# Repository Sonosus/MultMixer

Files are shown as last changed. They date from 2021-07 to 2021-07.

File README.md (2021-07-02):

# MultMixer
[][cc-by-sa]
hits (https://hits.deltapapa.io)

This is a Kosmo format module that is a combined buffered multiple and mixer. 
The multiple section has 1 input, 5 outputs, and an LED. The input is buffered to the 5 outputs, and the LED is used to show the state of the signal.

In the mixer section, there are 5 inputs and one output. Each input has its own pot and switch. The pot acts as an attenuator, and the switch disconnects that input from the main output. 





This module is based on the [LMNC Buffered Multiple](https://www.lookmumnocomputer.com/1161-buffered-multiple) and the [LMNC Mini Mixer](https://www.lookmumnocomputer.com/projects#/1163-mini-mixer). Much credit to Sam for open-sourcing his modules!

Interactive BOM [here](https://htmlpreview.github.io/?https://github.com/Sonosus/MultMixer/blob/main/Docs/MultMixer.html)

This work is licensed under a
[Creative Commons Attribution-ShareAlike 4.0 International License][cc-by-sa].

[][cc-by-sa]

[cc-by-sa]: http://creativecommons.org/licenses/by-sa/4.0/
[cc-by-sa-image]: https://licensebuttons.net/l/by-sa/4.0/88x31.png
[cc-by-sa-shield]: https://img.shields.io/badge/License-CC%20BY--SA%204.0-lightgrey.svg

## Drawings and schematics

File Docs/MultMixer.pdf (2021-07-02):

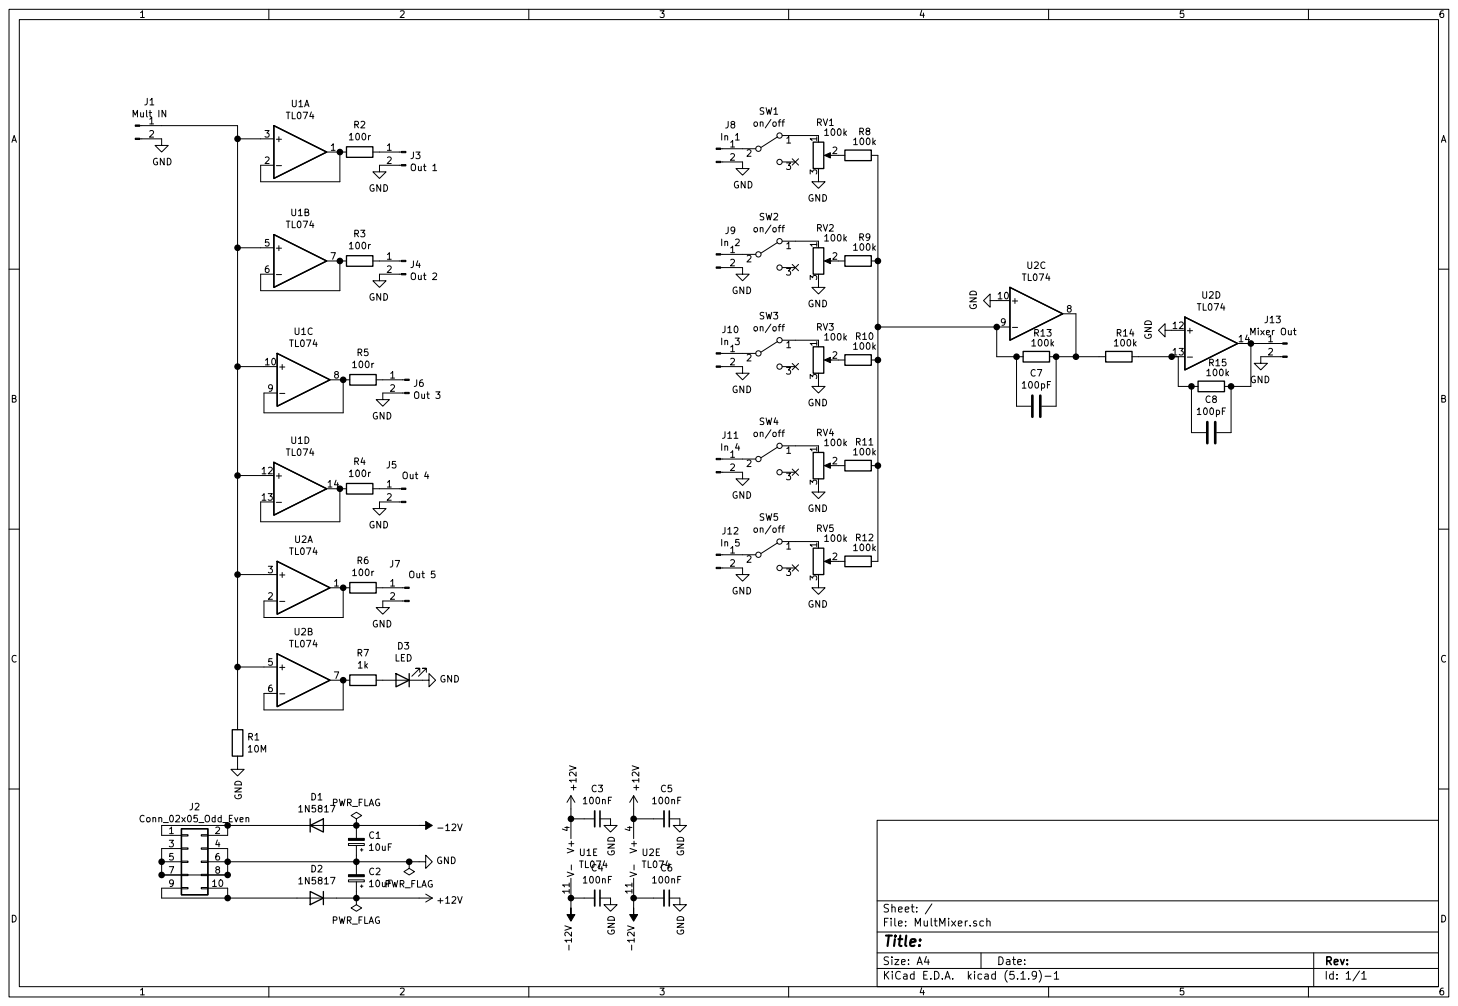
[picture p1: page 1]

Id: 1/1 Title: File: MultMixer.sch Sheet: /

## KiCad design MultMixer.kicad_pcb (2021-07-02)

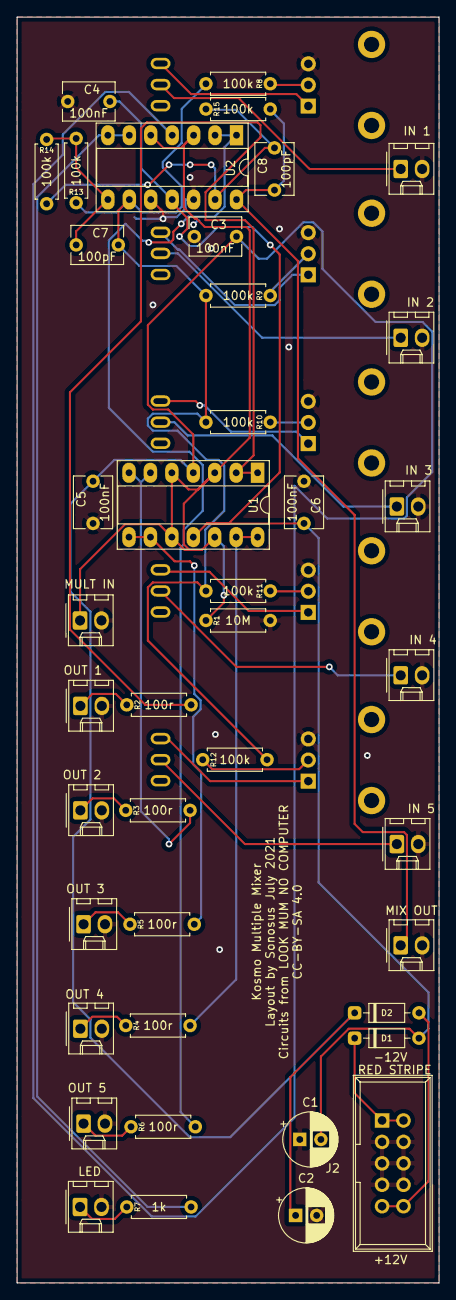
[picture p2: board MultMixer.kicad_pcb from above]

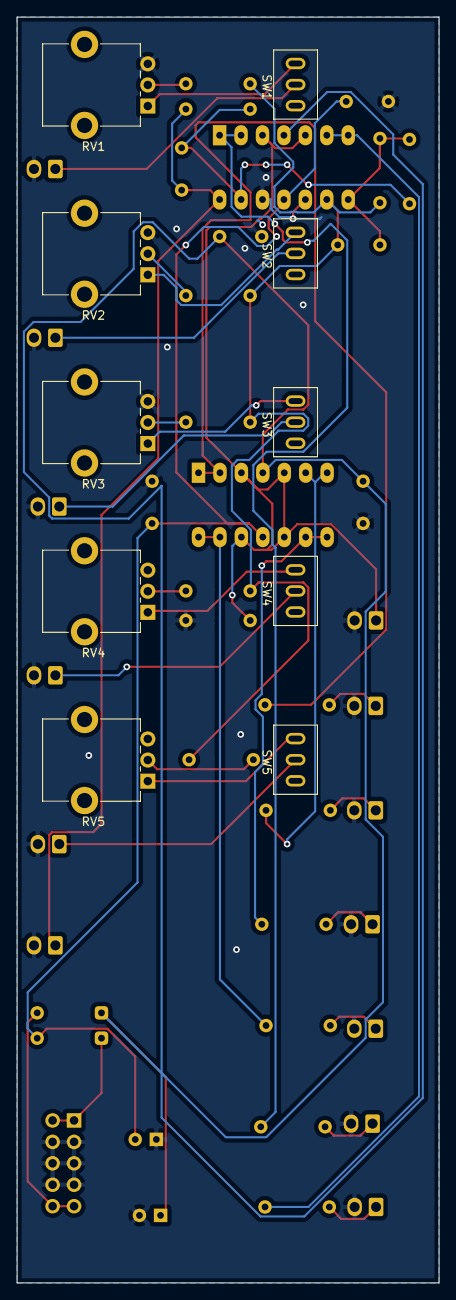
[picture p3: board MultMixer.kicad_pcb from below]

Board: 2 copper layers, 50.0 x 150.0 mm, 51 parts (10 on the bottom side), 37 nets.

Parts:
C1, C2: 10uF; Capacitor_Polarized
C3, C4, C5, C6: 100nF; Capacitor_NonPolarized
C7, C8: 100pF; Capacitor_NonPolarized
D1, D2: 1N5817; Diode_DO-35
IN 1: In 1; Molex_KK-254_AE-6410-02A_1x02_P2.54mm_Vertical
IN 2: In 2; Molex_KK-254_AE-6410-02A_1x02_P2.54mm_Vertical
IN 3: In 3; Molex_KK-254_AE-6410-02A_1x02_P2.54mm_Vertical
IN 4: In 4; Molex_KK-254_AE-6410-02A_1x02_P2.54mm_Vertical
IN 5: In 5; Molex_KK-254_AE-6410-02A_1x02_P2.54mm_Vertical
J2: Conn_02x05_Odd_Even; Power_Header
LED: LED; Molex_KK-254_AE-6410-02A_1x02_P2.54mm_Vertical
MIX OUT: Mixer Out; Molex_KK-254_AE-6410-02A_1x02_P2.54mm_Vertical
MULT IN: Mult IN; Molex_KK-254_AE-6410-02A_1x02_P2.54mm_Vertical
OUT 1: Out 1; Molex_KK-254_AE-6410-02A_1x02_P2.54mm_Vertical
OUT 2: Out 2; Molex_KK-254_AE-6410-02A_1x02_P2.54mm_Vertical
OUT 3: Out 3; Molex_KK-254_AE-6410-02A_1x02_P2.54mm_Vertical
OUT 4: Out 4; Molex_KK-254_AE-6410-02A_1x02_P2.54mm_Vertical
OUT 5: Out 5; Molex_KK-254_AE-6410-02A_1x02_P2.54mm_Vertical
R1: 10M; Resistor
R2, R3, R4, R5, R6: 100r; Resistor
R7: 1k; Resistor
R8, R9, R10, R11, R12, R13, R14, R15: 100k; Resistor
RV1, RV2, RV3, RV4, RV5: 100k; Potentiometer_Alpha_RD901F-40-00D_centred
SW1, SW2, SW3, SW4, SW5: on/off; SPST_Toggle_A-3643
U1, U2: TL074; DIP-14_Socket

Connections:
+12V: C2.1, C3.2, C5.2, D2.1, U1.4, U2.4
-12V: C1.2, C4.2, C6.2, D1.2, U1.11, U2.11
GND: C1.1, C2.2, C3.1, C4.1, C5.1, C6.1, IN 1.2, IN 2.2, IN 3.2, IN 4.2, IN 5.2, J2.3, J2.4, J2.5, J2.6, J2.7, J2.8, LED.1, MIX OUT.2, MULT IN.2, OUT 1.2, OUT 2.2, OUT 3.2, OUT 4.2, OUT 5.2, R1.2, RV1.3, RV2.3, RV3.3, RV4.3, RV5.3, U2.10, U2.12
unnamed: C7.1, R13.2, R14.1, U2.8
unnamed: C7.2, R8.2, R9.2, R10.2, R11.2, R12.2, R13.1, U2.9
unnamed: C8.1, MIX OUT.1, R15.2, U2.14
unnamed: C8.2, R14.2, R15.1, U2.13
unnamed: D1.1, J2.1, J2.2
unnamed: D2.2, J2.9, J2.10
unnamed: LED.2, R7.1
unnamed: MULT IN.1, R1.1, U1.3, U1.5, U1.10, U1.12, U2.3, U2.5
unnamed: OUT 1.1, R2.1
unnamed: OUT 2.1, R3.1
unnamed: OUT 4.1, R4.1
unnamed: OUT 3.1, R5.1
unnamed: OUT 5.1, R6.1
unnamed: IN 1.1, SW1.2
unnamed: IN 2.1, SW2.2
unnamed: IN 3.1, SW3.2
unnamed: IN 4.1, SW4.2
unnamed: IN 5.1, SW5.2
unnamed: R2.2, U1.1, U1.2
unnamed: R3.2, U1.6, U1.7
unnamed: R4.2, U1.13, U1.14
unnamed: R5.2, U1.8, U1.9
unnamed: R6.2, U2.1, U2.2
unnamed: R7.2, U2.6, U2.7
unnamed: R8.1, RV1.2
unnamed: R9.1, RV2.2
unnamed: R10.1, RV3.2
unnamed: R11.1, RV4.2
unnamed: R12.1, RV5.2
unnamed: RV1.1, SW1.1
unnamed: RV2.1, SW2.1
unnamed: RV3.1, SW3.1
unnamed: RV4.1, SW4.1
unnamed: RV5.1, SW5.1

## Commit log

2021-06-30 init kicad project
    [MultMixer.kicad_pcb, MultMixer.sch]
2021-06-30 add power header
    [MultMixer.sch]
2021-06-30 mult section
    [MultMixer.sch]
2021-06-30 op amp power
    [MultMixer.sch]
2021-06-30 start mixer section
    [MultMixer.sch]
2021-06-30 mixer section
    [MultMixer.sch]
2021-06-30 mixer power
    [MultMixer.sch]
2021-06-30 annotate and finish schem!
    [MultMixer.sch]
2021-06-30 place pots
    [MultMixer.kicad_pcb]
2021-07-01 output jack
    [MultMixer.sch]
2021-07-01 back annotate
    [MultMixer.sch]
2021-07-01 update pcb
    [MultMixer.kicad_pcb]
2021-07-01 relabel output
    [MultMixer.kicad_pcb, MultMixer.sch]
2021-07-02 almost done
    [MultMixer.kicad_pcb]
2021-07-02 schematic plot
2021-07-02 plot gerbers
    [MultMixer-B_Cu.gbr, MultMixer-B_Mask.gbr, MultMixer-B_SilkS.gbr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]
2021-07-02 zip gerbers
2021-07-02 interactive bom
2021-07-02 silkscreen text
    [MultMixer-B_Cu.gbr, MultMixer-B_Mask.gbr, MultMixer-B_SilkS.gbr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]

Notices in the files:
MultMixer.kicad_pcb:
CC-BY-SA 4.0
